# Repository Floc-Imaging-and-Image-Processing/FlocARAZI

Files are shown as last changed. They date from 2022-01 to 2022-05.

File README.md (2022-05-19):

# FlocARAZI
Parts list, build instructions, and image processing code for the FlocARAZI as described in:

Osborn, R., Dillon, B., Tran, D., Abolfazli, E., Dunne, K. B. J., Nittrouer, J. A., & Strom, K. (2021). FlocARAZI: An in-situ, image-based profiling instrument for sizing solid and flocculated suspended sediment. *Journal of Geophysical Research: Earth Surface*, 126, e2021JF006210. [https://doi.org/10.1029/2021JF006210](https://doi.org/10.1029/2021JF006210)



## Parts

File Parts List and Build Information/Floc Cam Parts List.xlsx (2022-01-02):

LED Parts | Price | Quantity | Total | Link | Stepper Motor Parts | Price | Quantity | Total | Link | Camera Parts | Price | Quantity | Total | Link | Blue Robotics Parts | Price | Quantity | Total | Link | McMaster parts | Price | Quantity | Total | Link | Miscellaneous parts | Price | Quantity | Total | Link |  | Tools | Price | Quantity | Total | Link
LED | 17.99 | 1 | 17.99 | http://www.mtnelectronics.com/index.php?route=product/product&product_id=407 | Stepper motor controller | 12.99 | 1 | 12.99 | https://www.amazon.com/Stepper-Controller-Generator-Regulator-15-160V/dp/B07QB1MFN4?s=gateway | PoE Injector | 20.26 | 1 | 20.26 | https://www.amazon.com/TRENDnet-Ethernet-Supported-Auto-MDIX-TPE-113GI/dp/B007Q87KP2?th=1 | Camera tube acrylic custom length (406mm) | 81.4 | 1 | 81.4 | https://bluerobotics.com/store/watertight-enclosures/3-series/wte3-p-tube-custom-r1/ | Stainless steel threaded rod | 19.64 | 1 | 19.64 | https://www.mcmaster.com/94185A580/ | Small Heat shrink kit | 8.99 | 1 | 8.99 | https://www.amazon.com/gp/product/B073R69KNB/ref=ox_sc_act_title_11?smid=A2JU42WM4PJ26Q&psc=1 |  | steel fish tape 125' | 22.99 | 1 | 22.99 | https://www.amazon.com/RamPro-Spring-Steel-Impact-Electric-Communication/dp/B01MXIOGF7
AC-DC power converter | 9.99 | 1 | 9.99 | https://www.amazon.com/gp/product/B06Y64QLBM/ref=ox_sc_act_title_1?smid=A3GP3KKILUBYIY&psc=1 | AC-DC power supply | 10.49 | 1 | 10.49 | https://www.amazon.com/gp/product/B07HNL5D56/ref=ox_sc_act_title_7?smid=A14FP9XIRL6C1F&psc=1 | Ethernet cable from injector to computer | 9.67 | 1 | 9.67 | https://www.amazon.com/Ethernet-IMONTA-Resistant-Waterproof-Buried-able/dp/B07H94M77Q | LED tube custom length (120mm) | 24 | 1 | 24 | https://bluerobotics.com/store/watertight-enclosures/3-series/wte3-p-tube-custom-r1/ | 18-8 stainless steel low profile screw | 8.4 | 1 | 8.4 | https://www.mcmaster.com/92855A335/ | Solder | 6.99 | 1 | 6.99 | https://www.amazon.com/SONEAK-Solder-Rosin-Electrical-Soldering/dp/B084RZF23H |  | hacksaw |  |  | 0
Power controller | 13.99 | 1 | 13.99 | https://www.amazon.com/gp/product/B07JZ2GQJF/ref=ox_sc_act_title_2?smid=AFHAE9RJVUMB&psc=1 | Stepper motor driver | 27.34 | 1 | 27.34 | https://www.omc-stepperonline.com/integrated-stepper-motor-driver-0-2a-10-28vdc-for-nema-8111417-stepper-motor | 225' cat6 ethernet cable | 104.68 | 2 | 209.36 | https://www.amazon.com/gp/product/B06XSKXCQ4/ref=ox_sc_act_image_7?smid=A27DUHPPTQX1VZ&psc=1 | Acrylic end cap | 10 | 2 | 20 | https://bluerobotics.com/store/watertight-enclosures/3-series/wte3-p-end-cap-r1/ | Button head hex drive screw | 6.55 | 1 | 6.55 | https://www.mcmaster.com/92095A187/ | loctite thread locker | 23.45 | 1 | 23.45 | https://www.amazon.com/Threadlocker-Medium-Strength-Resistant-Style/dp/B0000DD2YR |  | circular saw |  |  | 0
barrel power adapter | 0 | 1 | 0 | https://www.amazon.com/gp/product/B06Y64QLBM/ref=ox_sc_act_title_1?smid=A3GP3KKILUBYIY&psc=1 | Stepper motor w/ linear rail (150mm) | 89 | 1 | 89 | https://www.amazon.com/Linear-Actuator-Stepper-Milling-Machine/dp/B07K7HCHGC/?th=1 | 1' ethernet cable to camera | 13.99 | 1 | 13.99 | https://www.amazon.com/gp/product/B00HEM54DK/ref=ox_sc_act_title_6?smid=A1AMUYYA3CT6HJ&psc=1 | Spare O-Ring set | 3 | 3 | 9 | https://bluerobotics.com/store/watertight-enclosures/3-series/wte3-o-ring-set-r1/ | Button head hex drive screw | 4.57 | 1 | 4.57 | https://www.mcmaster.com/92095A201/ | power strip | 12.02 | 1 | 12.02 | https://www.amazon.com/GE-Outlet-Protector-Extension-14092/dp/B00DOMYL24 |  | Metal file |  |  | 0
Power cable bridge between both tubes |  | 1 | 0 |  | 3D printed stepper holder (motor side) |  |  | 0 |  | Heat shrink for ethernet cable | 28.074 | 5 | 140.37 | https://www.digikey.com/product-detail/en/Q2-F3X-1-01-MS50FT/Q2F3X100B-50-ND/1692287/?itemSeq=304403106 | O-Ring Flange | 24 | 4 | 96 | https://bluerobotics.com/store/watertight-enclosures/3-series/o-ring-flange-3-series/ | Stainless steel hex nut | 3.08 | 1 | 3.08 | https://www.mcmaster.com/94150A325/ | Stainless wire rope | 0.37 | 32 | 11.84 | https://www.homedepot.com/p/Everbilt-1-8-in-x-1-ft-Stainless-Steel-Uncoated-Wire-Rope-810056/204640740 | will want to purchase at home depot cut to length if no tool is available at the lab | heat gun | 129 | 1 | 129 | https://www.homedepot.com/p/Milwaukee-11-6-Amp-Variable-Temperature-Heat-Gun-8977-20/203407542
LED mount shaft (thorlabes) | 7.52 | 2 | 15.04 | https://www.thorlabs.com/thorproduct.cfm?partnumber=MS2R | 3D printed stepper holder (rail side) |  |  | 0 |  | carabeaners for ethernet cable | 26.99 | 1 | 26.99 | https://www.amazon.com/gp/product/B07L86XWMT/ref=ox_sc_act_title_5?smid=A3VVL1M01MGYPX&psc=1 | Enclosure Clamp | 36 | 2 | 72 | https://bluerobotics.com/store/watertight-enclosures/3-series/enclosure-clamp-3-series/ | High-speed steel drill-point countersink for screws | 23.05 | 1 | 23.05 | https://www.mcmaster.com/2756A49/ | Pelican Air 1615 | 321.95 | 1 | 321.95 | https://www.pelican.com/us/en/product/cases/air/1615?sku=016150-0001-150 |  | ethernet head crimper | 17.99 | 1 | 17.99 | https://www.amazon.com/TRENDnet-Crimping-Rj-45-Rj-12-TC-CT68/dp/B0000AZK4G
LED mount 90 degree (thorlabs) | 15.15 | 1 | 15.15 | https://www.thorlabs.com/thorproduct.cfm?partnumber=ER90B/M | Battery charger | 13.88 | 1 | 13.88 | https://www.amazon.com/gp/product/B07BYJTC94/ref=ox_sc_act_title_1?smid=A2G51RV0D5KLMK&psc=1 | F-F ethernet splitter to split 3D printed mount | 6.99 | 1 | 6.99 | https://www.amazon.com/Haitronic-ethernet-Connector-Ethernet-Extender/dp/B06XPZBRJ2 | Aluminum end cap with 4 holes | 12 | 2 | 24 | https://bluerobotics.com/store/watertight-enclosures/3-series/wte3-m-end-cap-4-hole-r1/ | High-speed steel round-shank reamer | 14.82 | 1 | 14.82 | https://www.mcmaster.com/2995A61/ | Nanuk 935 waterproof carry-on case | 153.89 | 1 | 153.89 | https://www.amazon.com/Nanuk-Waterproof-Hard-Wheels-Empty/dp/B00BP8UJCU |  | wood clamps for steadying ethernet during potting | 31.97 | 1 | 31.97 | https://www.amazon.com/IRWINQUICK-GRIPOne-Handed-Mini-Clamp-Pack-1964748/dp/B00TKIUL84
LED mounts clamp (thorlabs) | 17.85 | 1 | 17.85 | https://www.thorlabs.com/thorproduct.cfm?partnumber=MSRA90 | Battery 1500 mAh | 23.99 | 1 | 23.99 | https://www.amazon.com/gp/product/B07CV95YFN/ref=ox_sc_act_title_2?smid=A1KODDOPEPALCP&psc=1 | FLIR GIGE camera | 575 | 1 | 575 | https://www.flir.com/products/blackfly-s-gige/?model=BFS-PGE-120S4M-CS | M10 Cable Penetrator for 8mm cable | 5 | 2 | 10 | https://bluerobotics.com/store/cables-connectors/penetrators/penetrator-10-25-a-8mm-r2/ | 316 stainless steel hex drive flat head screw | 7.98 | 1 | 7.98 | https://www.mcmaster.com/93395A217/ | RJ45 ethernet break out board | 4.38 | 2 | 8.76 | https://www.amazon.com/Ethernet-Connector-Breakout-terminals-Spring/dp/B06XZ3BMTL |  | volt meter | 19.99 | 1 | 19.99 | https://www.amazon.com/Velleman-DVM850BL-Hold-Function-Backlight/dp/B00068U24A
3D Printed Mount |  | 1 | 0 |  | Battery power wire dean plug | 9.98 | 1 | 9.98 | https://www.amazon.com/T-Plug-T-Connectors-Deans-Style-BDHI-28/dp/B07MDGT5C1 | 3D Printed square to lift camera on rail platform |  | 1 | 0 |  | M10 cable penetrator for 6mm cable | 4 | 2 | 8 | https://bluerobotics.com/store/cables-connectors/penetrators/penetrator-10-25-a/ | Silver corner suface bracket | 7.62 | 6 | 45.72 | https://www.mcmaster.com/47065T267/ | spool core | 5.4 | 1 | 5.4 | https://www.mcmaster.com/38305T12/
Barrel power adapter for power cable |  | 2 | 0 |  | Power switch to turn battery on and off | 7.99 | 1 | 7.99 | https://www.amazon.com/DZS-Elec-Rocker-Switch-Position/dp/B07PMGXW2K | Screws to mount camera to platform |  |  | 0 |  | Enclosure vent and plug | 9 | 2 | 18 | https://bluerobotics.com/store/cables-connectors/penetrators/vent-asm-r1/ | silver corner bracket 2" | 5.25 | 9 | 47.25 | https://www.mcmaster.com/47065T239/ | spool flange | 8.24 | 1 | 8.24 | https://www.mcmaster.com/38305T33/
Heat sink | 10.74 | 1 | 10.74 | https://www.amazon.com/a16012800ux0575-Aluminium-Heatsink-Radiator-25x25x10/dp/B01FLDT0WE?s=electronics |  |  |  |  |  | camera to tube adapter (thorlabs SM1A9) | 19.96 | 1 | 19.96 | https://www.thorlabs.com/thorproduct.cfm?partnumber=SM1A9 | M10 cable penetrator blank | 4 | 2 | 8 | https://bluerobotics.com/store/cables-connectors/penetrators/penetrator-blank-10-25-a-r2/ | silver corner bracket 1" | 5.21 | 8 | 41.68 | https://www.mcmaster.com/47065T236/ | 3D printed led and stepper controller housing |  |  | 0
Thermal glue | 9.98 | 1 | 9.98 | https://www.amazon.com/GENNEL-Conductive-Silicone-Adhesive-Compound/dp/B072MSXHJD?s=gateway |  |  |  |  |  | 3" tube | 27.84 | 1 | 27.84 | https://www.thorlabs.com/thorproduct.cfm?partnumber=SM1L30 | Penetrator wrench | 13 | 2 | 26 | https://bluerobotics.com/store/cables-connectors/tools/tool-penetrator-wrench-r1/ | surface tee surface bracket | 7.95 | 1 | 7.95 | https://www.mcmaster.com/47065T278/ | Zip ties | 15 | 1 | 15 | https://www.amazon.com/Cambridge-ZipIts-Assortment-Nylon-Cable/dp/B00PB0KO7I
 |  |  |  |  |  |  |  |  |  | retaining ring | 4.64 | 1 | 4.64 | https://www.thorlabs.com/thorproduct.cfm?partnumber=SM1RR | Potting kit | 10 | 1 | 10 | https://bluerobotics.com/store/cables-connectors/tools/tool-potting-kit-r1/ | t-slotted framing 1" | 30.54 | 3 | 91.62 | https://www.mcmaster.com/47065T101-47065T977/ | Cat6 End | 7.99 | 1 | 7.99 | https://www.amazon.com/CableCreation-Connector-Ethernet-Connectors-Transparent/dp/B01K9Z4C3G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
 |  |  |  |  |  |  |  |  |  | Aperture (SM1D12D) | 71.15 | 1 | 71.15 | https://www.thorlabs.com/thorproduct.cfm?partnumber=SM1D12D#ad-image-0 | Loctite marine epoxy | 6 | 2 | 12 | https://bluerobotics.com/store/cables-connectors/tools/loctite-marine-epoxy/ | 18-8 stainless steel socket head screw | 10.63 | 1 | 10.63 | https://www.mcmaster.com/92196A948/
 |  |  |  |  |  |  |  |  |  | aperture to objective adapter | 21.31 | 1 | 21.31 | https://www.thorlabs.com/thorproduct.cfm?partnumber=SM1A27 | Acetone cable preparation wipes | 4 | 1 | 4 | https://bluerobotics.com/store/cables-connectors/tools/potting-acetone-wipes-qty10-r1-rp/ | 18-8 Stainless Steel Nylon-Insert Locknut | 3.95 | 1 | 3.95 | https://www.mcmaster.com/91831A002/
 |  |  |  |  |  |  |  |  |  | F=75mm mitutoyo corrective lens (AC254-075-A) | 81.16 | 1 | 81.16 | https://www.thorlabs.com/thorproduct.cfm?partnumber=AC254-075-A | Moisture indicating silica gel desiccant bag | 10 | 1 | 10 | https://bluerobotics.com/store/watertight-enclosures/enclosure-tools-supplies/desiccant-r2-rp/ | 18-8 Stainless Steel Socket Head Screw | 9.75 | 1 | 9.75 | https://www.mcmaster.com/92196A033/
 |  |  |  |  |  |  |  |  |  | Mitutoyo 5x objective | 720 | 1 | 720 | https://www.edmundoptics.com/p/5x-mitutoyo-plan-apo-infinity-corrected-long-wd-objective/6621/ | Hand operated vacuum pump | 34 | 1 | 34 | https://bluerobotics.com/store/watertight-enclosures/enclosure-tools-supplies/hand-operated-vacuum-pump/ | 18-8 Stainless Steel Nylon-Insert Locknut | 5.31 | 1 | 5.31 | https://www.mcmaster.com/93625A100/
 |  |  |  |  |  |  |  |  |  | Throlab retaining ring tool(SPW602) | 28.38 | 1 | 28.38 | https://www.thorlabs.com/thorproduct.cfm?partnumber=SPW602 | O-ring pick | 4 | 1 | 4 | https://bluerobotics.com/store/watertight-enclosures/enclosure-tools-supplies/tool-o-ring-pick-r1/ | Button Head Hex Drive Screw | 5.72 | 1 | 5.72 | https://www.mcmaster.com/92095A106/
 |  |  |  |  |  |  |  |  |  |  |  |  |  |  | Silicone Grease | 3 | 1 | 3 | https://bluerobotics.com/store/watertight-enclosures/enclosure-tools-supplies/tool-silicone-grease-10g-r1/ | Button Head Hex Drive Screw | 4 | 1 | 4 | https://www.mcmaster.com/92095A475/
 |  |  |  |  |  |  |  |  |  |  |  |  |  |  |  |  |  |  |  | Pear-Shaped Link | 9.59 | 2 | 19.18 | https://www.mcmaster.com/3567T31/
 |  |  |  |  |  |  |  |  |  |  |  |  |  |  |  |  |  |  |  | 18-8 Stainless Steel Cast Wire Rope Clamp | 1.46 | 34 | 49.64 | https://www.mcmaster.com/31985T71/
 |  |  |  |  |  |  |  |  |  |  |  |  |  |  |  |  |  |  |  | Extra-Stretch Extension Spring | 40.52 | 1 | 40.52 | https://www.mcmaster.com/8433K47/
 |  |  |  |  |  |  |  |  |  |  |  |  |  |  |  |  |  |  |  | Silver Square Mounting Plate | 12.02 | 2 | 24.04 | https://www.mcmaster.com/47065T651/
 |  |  |  |  |  |  |  |  |  |  |  |  |  |  |  |  |  |  |  | aluminum sheet metal for rear fin (14.5x12x1/8 inch) |  | 1
 |  |  |  |  |  |  |  |  |  |  |  |  |  |  |  |  |  |  |  | t-slotted framing 1"x2" |  |  |  | https://www.mcmaster.com/47065T107/
 |  |  | 110.73 |  |  |  |  | 195.66 |  |  |  |  | 1977.07 |  |  |  |  | 473.4 |  |  |  |  | 495.05 |  |  |  |  | 584.52 |  |  |  |  |  | 221.94
Total | 3251.91
w/ misc. | 3968.9

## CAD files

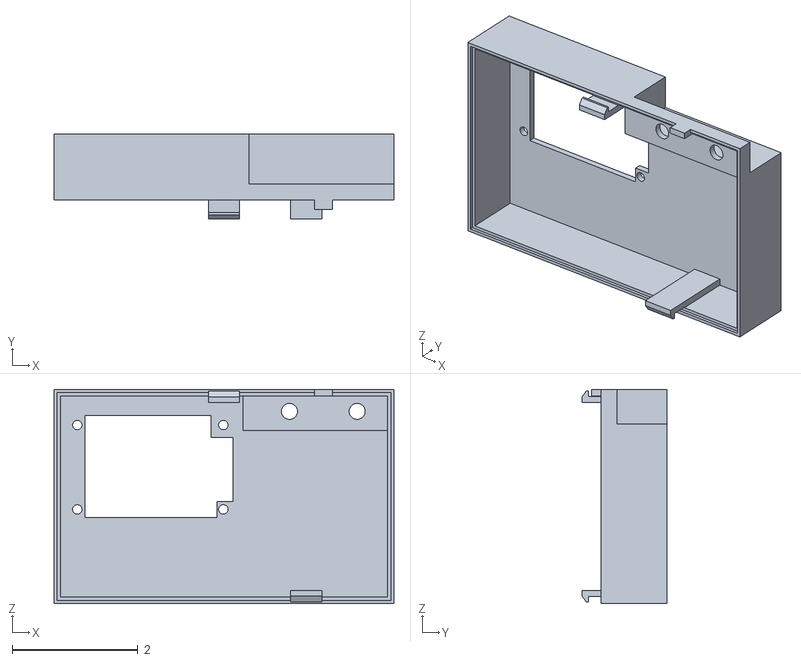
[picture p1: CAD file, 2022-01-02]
Parts List and Build Information/CAD Files/housing top.stl
5.40 x 1.35 x 3.40

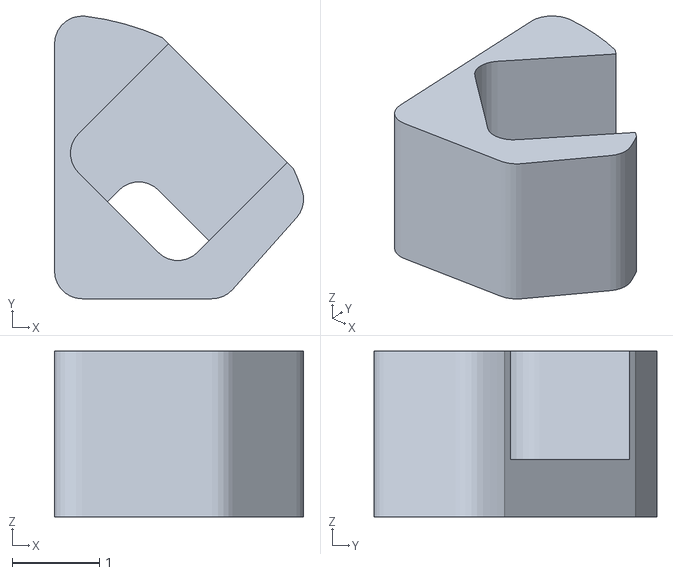
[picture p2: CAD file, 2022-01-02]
Parts List and Build Information/CAD Files/BatterySwitchHolder.stl
2.86 x 3.25 x 1.90

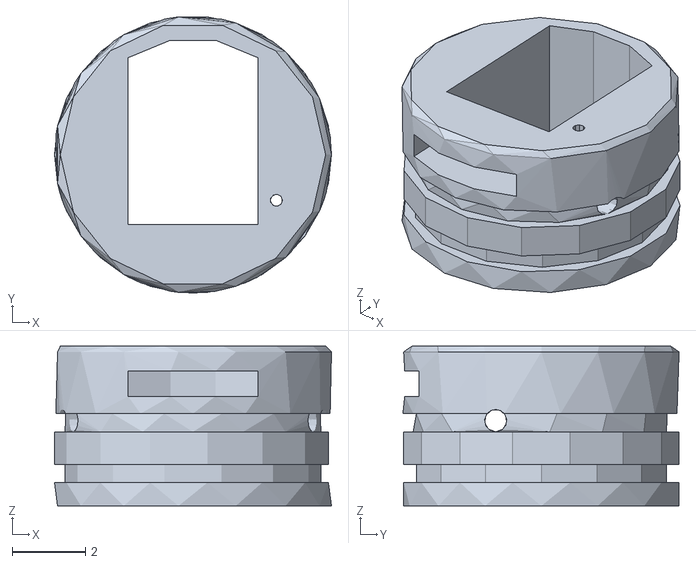
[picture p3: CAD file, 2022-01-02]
Parts List and Build Information/CAD Files/LEDSlideHolder.stl
7.55 x 7.53 x 4.36

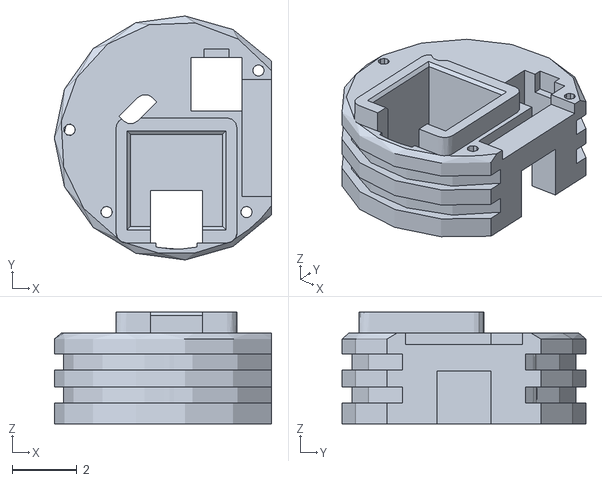
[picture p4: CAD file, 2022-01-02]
Parts List and Build Information/CAD Files/CameraBackSupport.stl
6.71 x 7.53 x 3.44

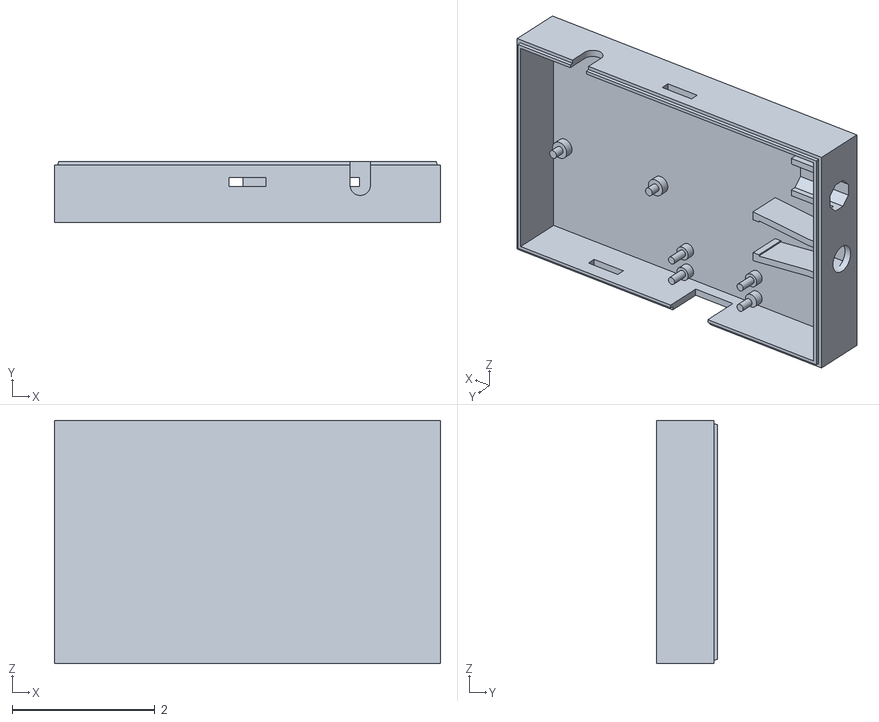
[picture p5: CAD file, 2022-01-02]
Parts List and Build Information/CAD Files/Housing v2.stl
5.40 x 0.85 x 3.40

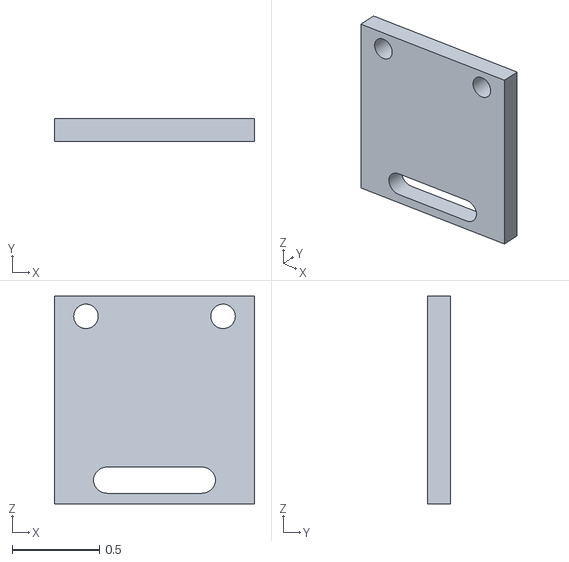
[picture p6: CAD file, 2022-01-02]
Parts List and Build Information/CAD Files/camera shim.stl
1.14 x 0.13 x 1.19

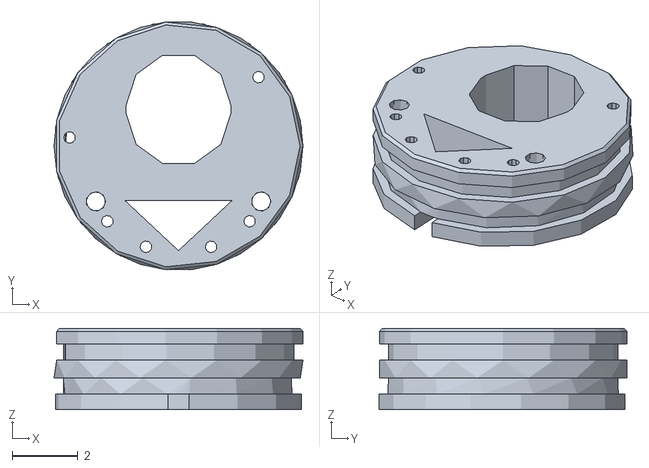
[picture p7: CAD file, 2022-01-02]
Parts List and Build Information/CAD Files/CameraFrontSupport.stl
7.55 x 7.51 x 2.46

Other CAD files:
Parts List and Build Information/CAD Files/BatterySwitchHolder.ipt
Parts List and Build Information/CAD Files/CameraBackSupport.ipt
Parts List and Build Information/CAD Files/CameraFrontSupport.ipt
Parts List and Build Information/CAD Files/Housing v2.ipt
Parts List and Build Information/CAD Files/LEDSlideHolder.ipt
Parts List and Build Information/CAD Files/camera shim.ipt
Parts List and Build Information/CAD Files/housing top.ipt

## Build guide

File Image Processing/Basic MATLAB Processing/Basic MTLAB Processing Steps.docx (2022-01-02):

Step 1: Sort the images collected in the field to obtain a folder containing only the good images that you would like to process. For this step, I have been using the free photo sorting software PhotoSift (https://www.rlvision.com/photosift/about.php). I like this method because you can load your collected images into PhotoSift and sort the images into folders by simply pressing any letter on the keyboard, directing the image to a specified folder. For example, I usually choose to press the “g” key for good images and “b” for bad images.

Step 2: With the images sorted into the “good” folder from step 1, process the images with the MATLAB code. You want the data from all of the collected images to be contained within a single text file. This can be accomplished by pasting the processing code to the directory immediately above the folder that contains all of the good images. Within the Renamer_file_name_folder_ehsan.m file, setting the input parameter “count” at the top of this file to 1 will process all of the images from the good images folder and store the output data in a single text file. The files that need to be in the directory above the folder with the good images include: (1) gaussgradient.m (2) Matlab_code.m (3) Renamer_filer_name_folder_ehsan.m (4) ij.jar (5) ImageJ_code.bat and (6) ImageJ_code.txt. In the directory above where the aforementioned 6 files are located, the files (1) movefiles.m and (2) sort_nat.m should be present.

You should then be ready to run the processing code by running the Renamer_filer_name_folder_ehsan.m file within MATLAB.

The outputted text file folder from processing will show up in the directory containing the images folder and the 6 files needed for processing. The folder will be named “Output_text_files_subtracted”

I have been saving all particles identified by imageJ, then filtering particles within python based on “clarity” from the out of focus filter. However, this can result in an overwhelming number of particles in the outputted text file if you are processing a large number of image (> ~1000). The out of focus particles can be excluded from the outputted text file by modifying line 93 of the Matlab_code.m file.

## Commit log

2022-01-02 Initial code upload
    Initial code upload
    [Combined_TrainData.xlsx]
2022-01-02 updated folder name
    [Combined_TrainData.xlsx]
2022-01-02 initial build upload
    [BatterySwitchHolder.ipt, BatterySwitchHolder.stl, CameraBackSupport.ipt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]
